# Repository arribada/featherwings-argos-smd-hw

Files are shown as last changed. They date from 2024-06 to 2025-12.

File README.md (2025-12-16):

N|Solid
# Feather Wings argos SMD breakout
## Description 

**Feather Wing for the ARGOS-SMD module. **

This breakout board can be used with a Feather board (from Adafruit) to connect the ARGOS-SMD module. 
It exposes the ARGOS-SMD module pins to the Feather board and includes a specific LDO to power the RF amplifier.

[Details of SMD argos repository.](https://github.com/arribada/argos-smd-hw)

This repository is an altium project with the production files. Please download the [hardware-lib](https://github.com/arribada/hardware-lib ) if you want full sources files (device sheet + library). 

## Components:

The RSPB tracker include the following components:
 - argos-smd
 - TPS63901 => power for RF amplifier

## Quick start

 - Connect Adafruit Feather nRF52840 (the Feather will provide 3V3 for SMD and VBAT or VBUS for Power Amplifier SMD)
 - Upload [Arduino sample](https://github.com/arribada/argos-smd-test-arduino) code or [Zephyr driver](https://github.com/arribada/argos-smd-driver-zephyr)
 - Communicate with KimGUI or Serial link with J6 connector
   or
 - Communicate to the SMD via the Adafruit Feather.

## Pin out 

Check Wiki page.

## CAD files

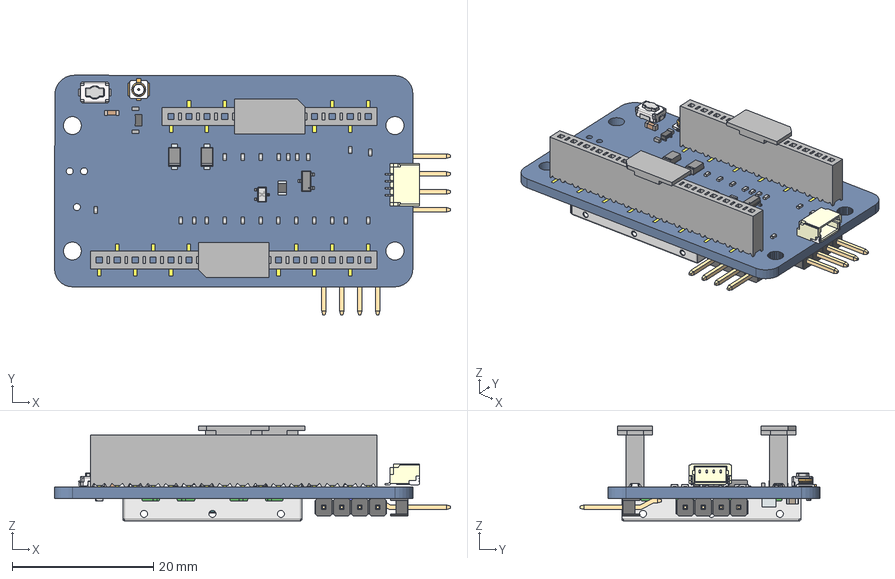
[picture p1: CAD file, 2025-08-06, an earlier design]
Project Outputs for Wings_SMD_Breakout/featherwings-argos-smd_v1.0/Wings_SMD_Breakout_v1.0.step
56.1 x 34.0 x 13.5 mm
M20-88904_MOULD x 2
M20-889_CONTACT x 8
36103255S
term1 x 12
term2 x 12
TL1015 BODY
TL1015 COVER
TL1015 ACTUATOR
TL1015 TERM x 2
Extruded x 60
Rect1 x 2
Rect2 x 2
Rect3 x 2
Rect4 x 2
Rect5 x 2
Rect6 x 2
Rect7 x 2
Rect8 x 2
Rect9 x 2
Rect10 x 2
Rect11 x 2
Chip Inductor 0603
A1
A2
A4
A5
A7
A8
A9
B1
B2
B3
B4
B5
B6
B7
B8
B9
C1
C2
C3
C4
C5
C6
C7
C8
D2
D3
D4
D5
D6
D7
D8
D9
E1
E2
E3
E4
E5
E6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

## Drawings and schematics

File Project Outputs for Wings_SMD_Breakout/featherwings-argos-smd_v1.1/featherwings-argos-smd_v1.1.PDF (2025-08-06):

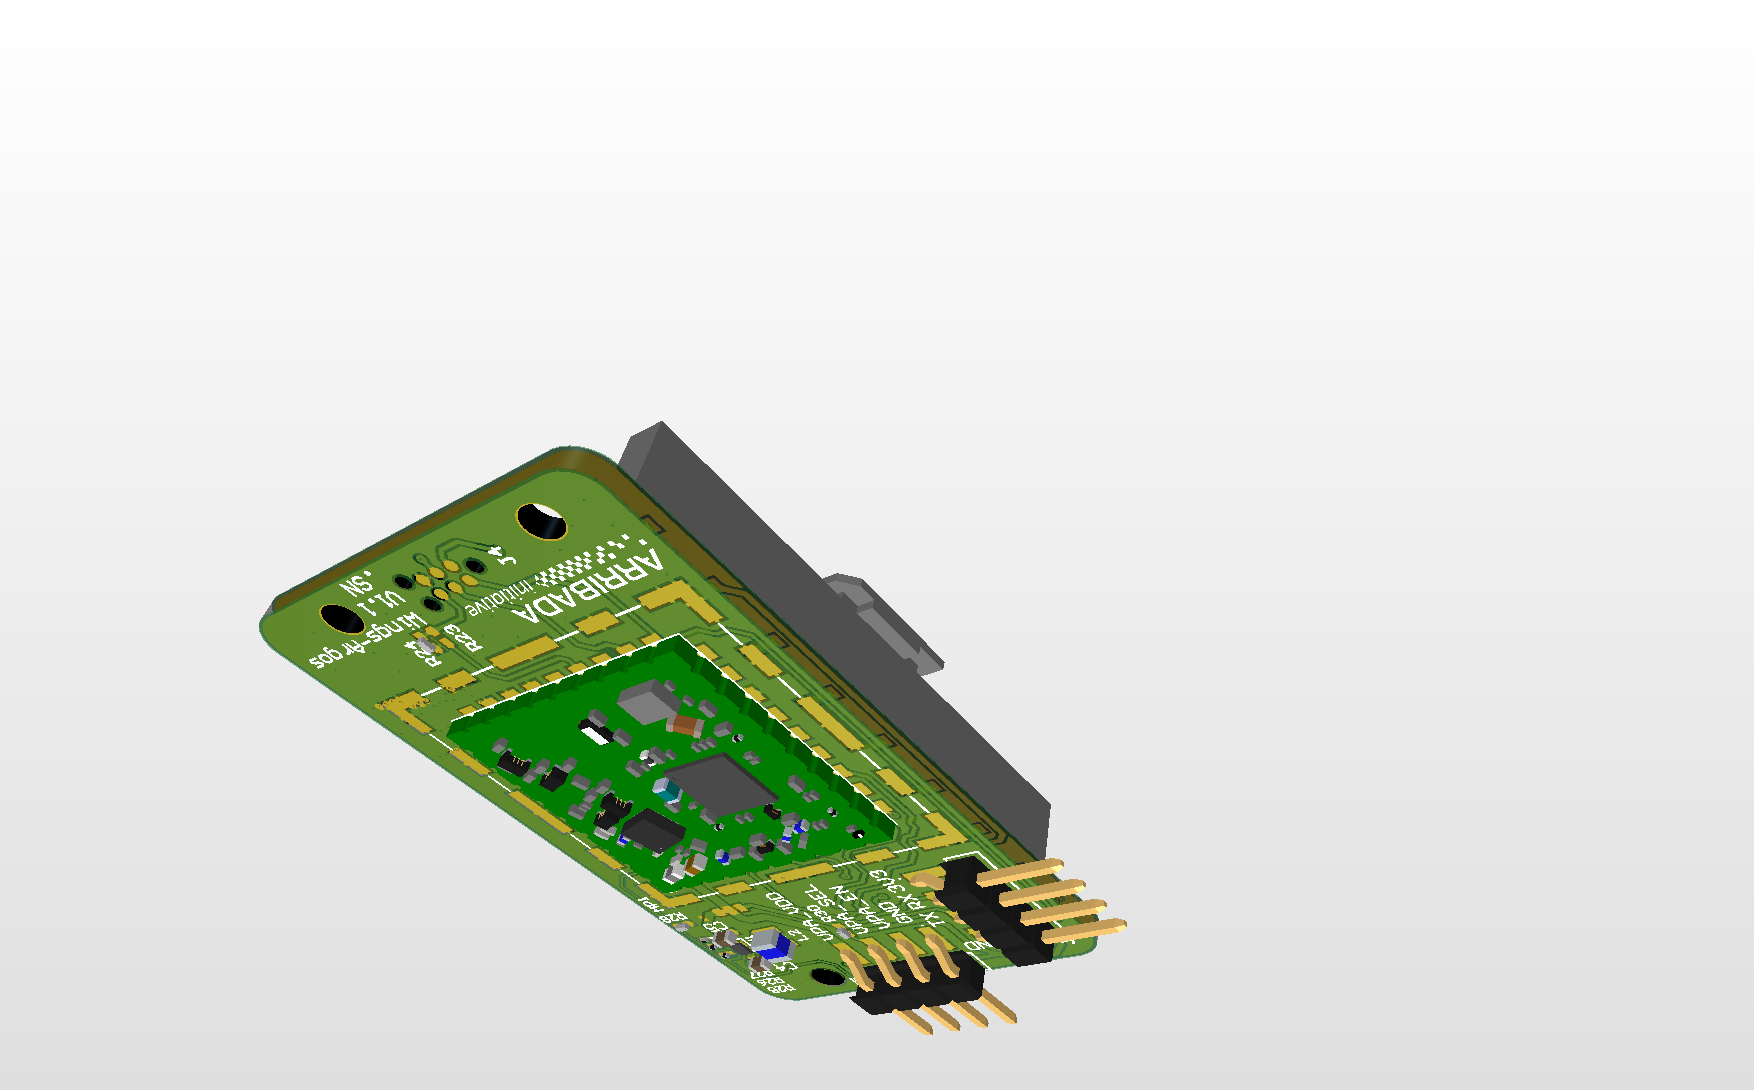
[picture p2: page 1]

D | D
C | C
B | B
A | A

Arribada Initiative
https://github.com/arribada contact@arribada.org
arribada.org
3 | UK - Portsmouth

## HorizonLink-Wings_Breakout

smd-wings | B
06/08/2025 | 15:22:21
C:\Users\fourn\Altium\AD25\Projects\Arribada\featherwings-argos-smd-hw\Project_Overview.SchDoc

Title

Size: | Reference:

Date:
File:

Revision:

Time: | Sheet | of
A4 | 1.1
Table of contents | Legend

General comment such as function title, configuration, ...

Sheet 2: SMD_Breakout | Text to be added to silkscreen.

Sheet 1: Project overview (this page)

# HorizonLink-Wings_Breakout

# smd-wings

Sheet 3: TPS63901_BuckBoost_lowIq_3V3_400mA

Device Sheets: | Warning text.

# OPEN HARDWARE LICENSE AGREEMENT

smd-wings

Feather wing for the ARGOS-SMD module. This breakout board can be used with a Feather board (from Adafruit) to connect the ARGOS-SMD module. It exposes the ARGOS-SMD module pins to the Feather board and includes a specific LDO to power the RF amplifier.

The Open Hardware License Agreement (“Agreement”) is a binding legal contract between you ("You") and the creators of this design, as represented by the Arribada Initiative, under the terms of the GNU General Public License version 3 (“GPLv3”). This license governs the use, modification, and distribution of the open-design PCB and any associated design files or materials (collectively referred to as the “Reference Material”).

By accessing, using, or modifying the Reference Material, You agree to be bound by the terms and conditions of the GPLv3. If you do not agree to these terms, do not use the Reference Material. Your use of the Reference Material constitutes acceptance of this Agreement.

The complete GNU General Public License version 3 can be found at www.gnu.org/licenses/gpl-3.0.html.

For more details about this open-design PCB project and its licensing, please visit the Arribada Initiative website or contact us directly.

Notes to generate the
board layout.

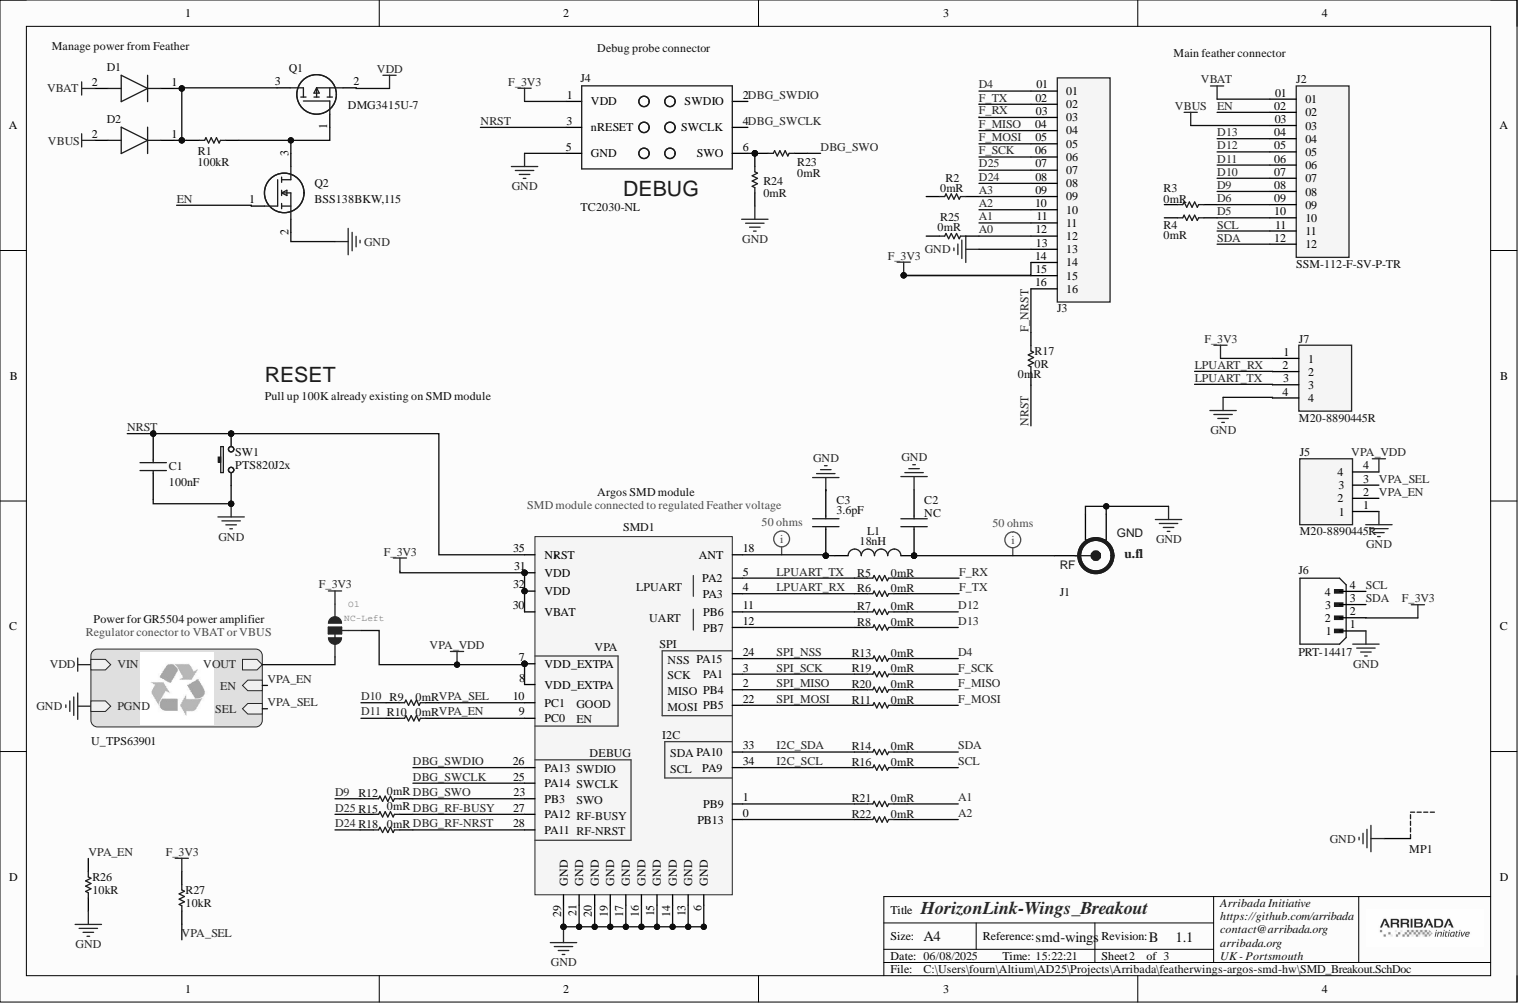
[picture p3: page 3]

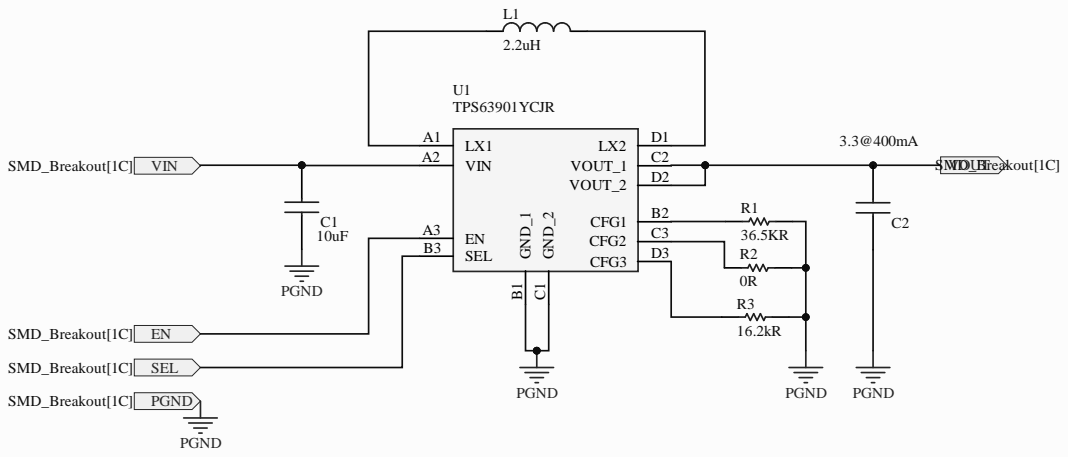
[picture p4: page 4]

# Board Stack Report

Stack Up | Layer Stack
Layer | Board Layer Stack | Name | Material | Thickness | Constant

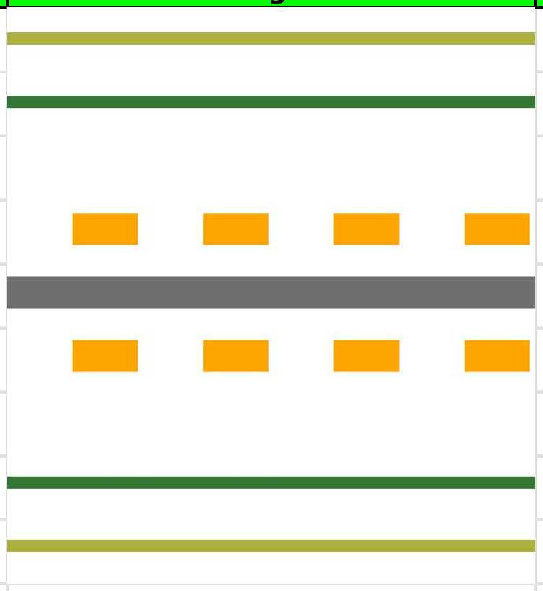
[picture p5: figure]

1 | | Top Overlay | | 0mil
2 | | Top Solder | SM-001 | 1mil | 4
3 | | Top Surface Finish | PbSn | 0.787mil
4 | | Top Layer | CF-004 | 1.378mil
5 | | Dielectric 1 | Core-043 | 59mil | 4.3
6 | | Bottom Layer | CF-004 | 1.378mil
7 | | Bottom Surface Finish | PbSn | 0.787mil
8 | | Bottom Solder | SM-001 | 1mil | 4
9 | | Bottom Overlay | | 0mil
| Height : 65.331mil

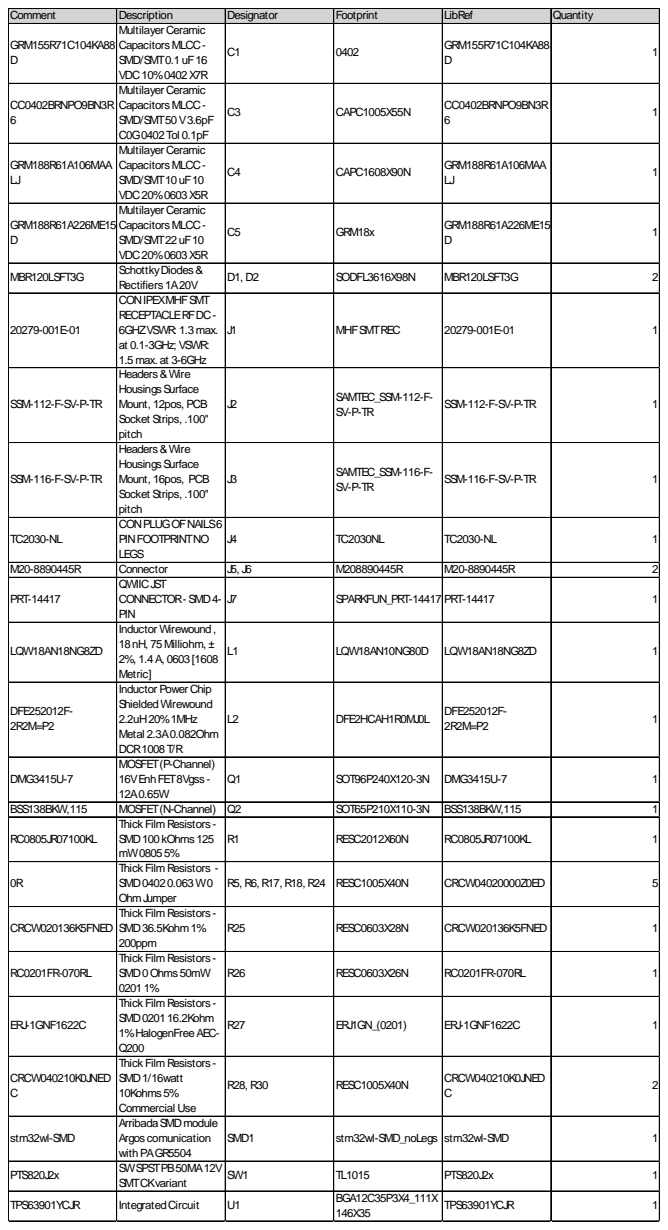
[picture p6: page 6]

Comment | Description | Designator | Footprint | LibRef | Quantity
GRM155R71C104KA88 | Multilayer Ceramic CapacitorsMLCC-SMD/SMT0.1 uF16 VDC10%0402X7R | C1 | 0402 | GRM155R71C104KA88 D | 1

CC0402BRNPO9BN3R 6 | Multilayer Ceramic CapacitorsMLCC-SMD/SMT50V3.6pF C0G0402Tol 0.1pF | C3 | CAPC1005X55N | CC0402BRNPO9BN3R 6 | 1

GRM188R61A106MAA LJ | Multilayer Ceramic CapacitorsMLCC-SMD/SMT10uF10 VDC20%0603X5R | C4 | CAPC1608X90N | GRM188R61A106MAA LJ | 1

GRM188R61A226ME15 D | Multilayer Ceramic CapacitorsMLCC-SMD/SMT22uF10 VDC20%0603X5R | C5 | GRM18x | GRM188R61A226ME15 D | 1

MBR120LSFT3G | SchottkyDiodes& Rectifiers1A20V | D1, D2 | SODFL3616X98N | MBR120LSFT3G | 2

20279-001E-01 | CONIPEXMHFSMT RECEPTACLERFDC-6GHZVSWR: 1.3 max. at 0.1-3GHz; VSWR: 1.5 max. at 3-6GHz | J1 | MHFSMTREC | 20279-001E-01 | 1

SSM-112-F-SV-P-TR | Headers&Wire HousingsSurface Mount, 12pos, PCB Socket Strips, .100" pitch | J2 | SAMTEC_SSM-112-F-SV-P-TR | SSM-112-F-SV-P-TR | 1

SSM-116-F-SV-P-TR | Headers&Wire HousingsSurface Mount, 16pos, PCB Socket Strips, .100" pitch | J3 | SAMTEC_SSM-116-F-SV-P-TR | SSM-116-F-SV-P-TR | 1

TC2030-NL | CONPLUGOFNAILS6 PINFOOTPRINTNO LEGS | J4 | TC2030NL | TC2030-NL | 1

M20-8890445R | Connector | J5, J6 | M208890445R | M20-8890445R | 2
PRT-14417 | QWIICJST CONNECTOR- SMD4-PIN | J7 | SPARKFUN_PRT-14417 PRT-14417 | | 1

LQW18AN18NG8ZD | Inductor Wirewound, 18nH, 75Milliohm, ± 2%, 1.4A, 0603[1608 Metric] | L1 | LQW18AN10NG80D | LQW18AN18NG8ZD | 1

DFE252012F-2R2M=P2 | Inductor Power Chip ShieldedWirewound 2.2uH20%1MHz Metal 2.3A0.082Ohm DCR1008T/R | L2 | DFE2HCAH1R0MJ0L | DFE252012F-2R2M=P2 | 1

DMG3415U-7 | MOSFET(P-Channel) 16VEnhFET8Vgss -12A0.65W | Q1 | SOT96P240X120-3N | DMG3415U-7 | 1

BSS138BKW,115 | MOSFET(N-Channel) | Q2 | SOT65P210X110-3N | BSS138BKW,115 | 1
RC0805JR07100KL | Thick Film Resistors -SMD100kOhms125 mW08055% | R1 | RESC2012X60N | RC0805JR07100KL | 1
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

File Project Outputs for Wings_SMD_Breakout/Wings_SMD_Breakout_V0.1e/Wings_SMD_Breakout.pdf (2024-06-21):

D | D
C | C
B | B
A | A

Arribada Initiative
https://github.com/arribada contact@arribada.org
arribada.org
3 | UK - Portsmouth

## HorizonLink-Wings_Breakout

wings-smd | 0.1
21/06/2024 | 11:32:49
D:\Altium\Projects\stm32wl-dev\Projects\Wings_SMD_Breakout\Project_Overview.SchDoc

Title

Size: | Reference:

Date:
File:

Revision:

Time: | Sheet | of
A4 | e
Table of contents | Legend

General comment such as function title, configuration, ...

Sheet 2: SMD_Breakout | Text to be added to silkscreen.

Sheet 1: Project overview (this page)

# HorizonLink-Wings_Breakout

# wings-smd

Sheet 3: TPS62A01DRL_Buck_3V3

Device Sheets: | Warning text.

# OPEN PLATFORM LICENSE AGREEMENT

The Open Platform License Agreement (“Agreement”) is a binding legal contract between you ("You")

and STMicroelectronics International N.V. (“ST”), a company incorporated under the laws of the

Netherlands acting for the purpose of this Agreement through its Swiss branch 39, Chemin du

Champ des Filles, 1228 Plan-les-Ouates, Geneva, Switzerland.

By using the enclosed reference designs, schematics, PC board layouts, and documentation, in hardcopy

or CAD tool file format (collectively, the “Reference Material”), You are agreeing to be bound by

the terms and conditions of this Agreement. Do not use the Reference Material until You have read

and agreed to this Agreement terms and conditions. The use of the Reference Material automatically

implies the acceptance of the Agreement terms and conditions.

The complete Open Platform License Agreement can be found on www.st.com/opla.

U_SMD_Breakout
SMD_Breakout.SchDoc

Notes to generate the
board layout.

Feather wing for the ARGOS-SMD module. This breakout board can be used with a Feather board (from Adafruit) to connect the ARGOS-SMD module. It exposes the ARGOS-SMD module pins to the Feather board and includes a specific LDO to power the RF amplifier.

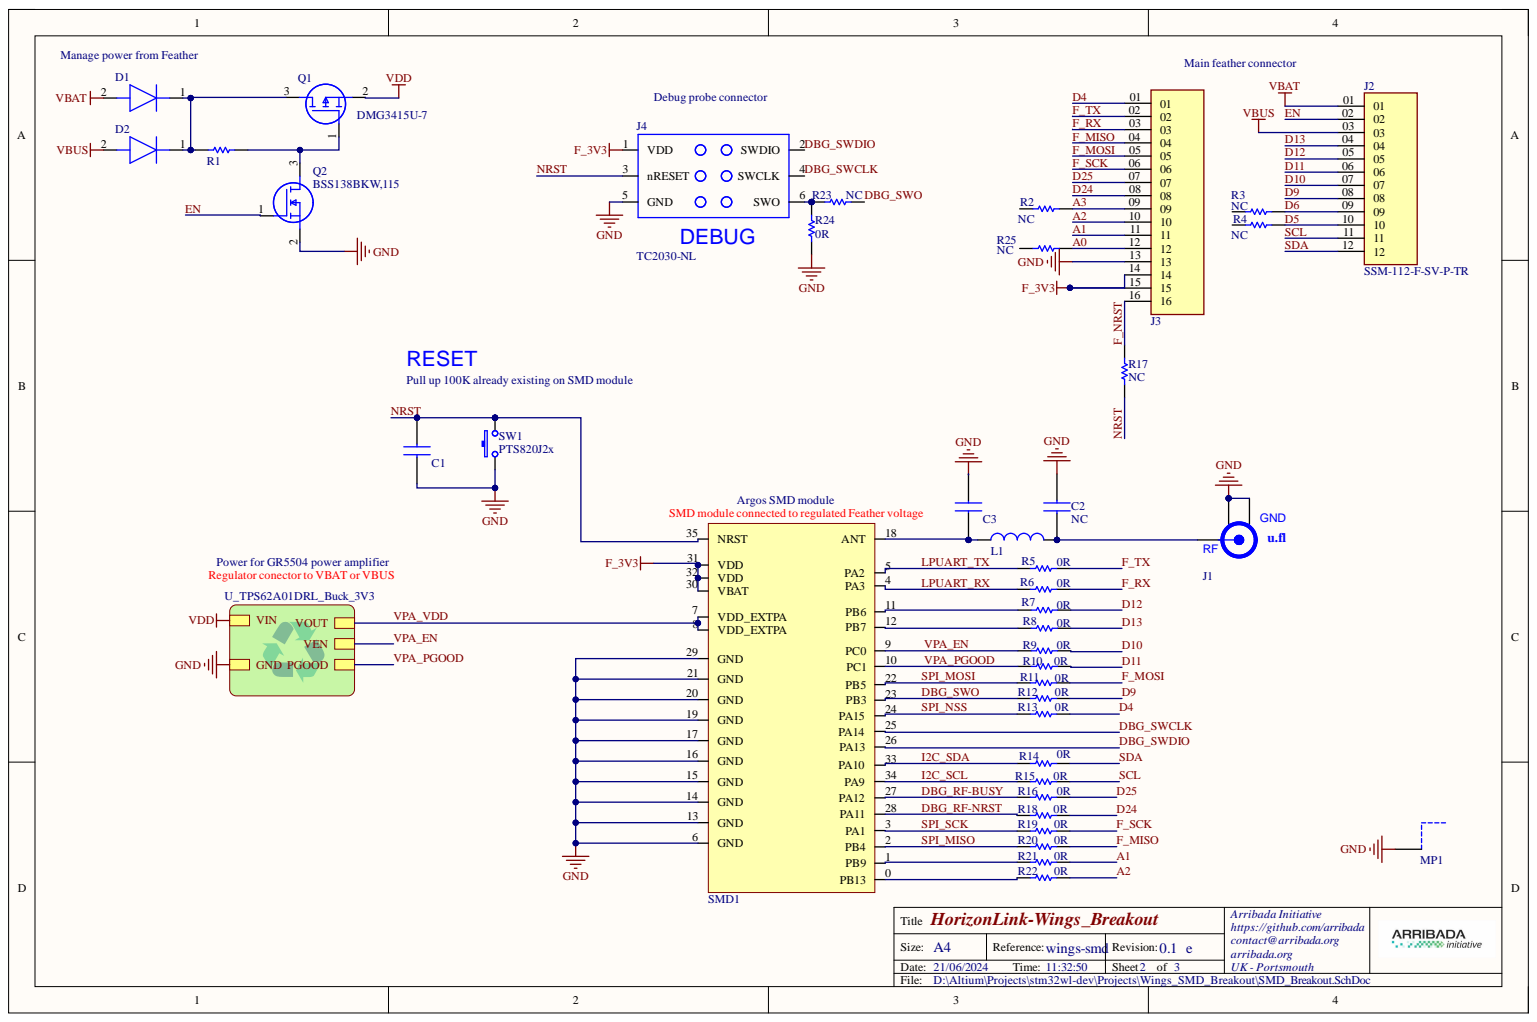
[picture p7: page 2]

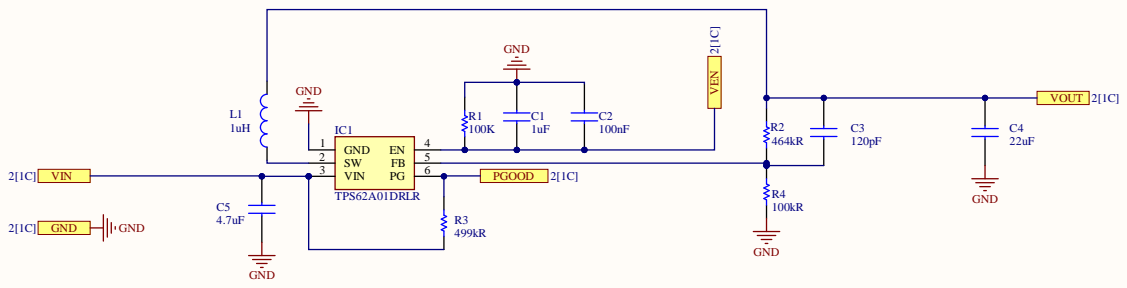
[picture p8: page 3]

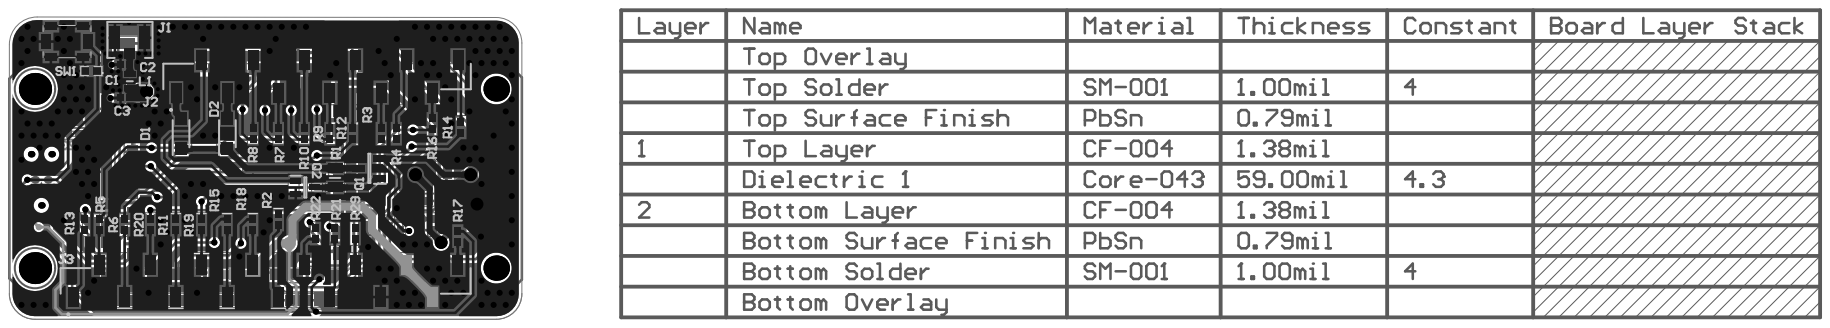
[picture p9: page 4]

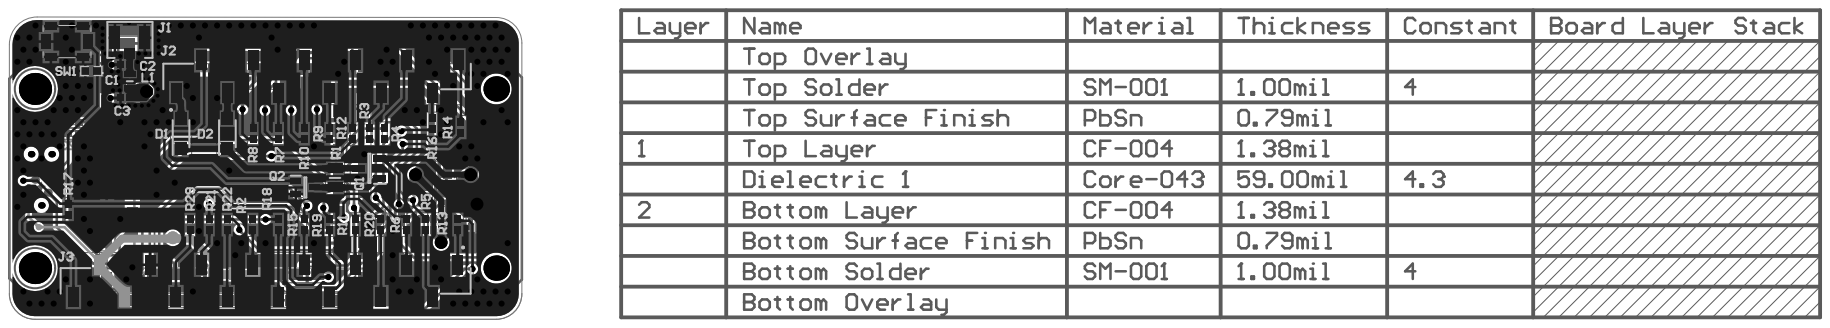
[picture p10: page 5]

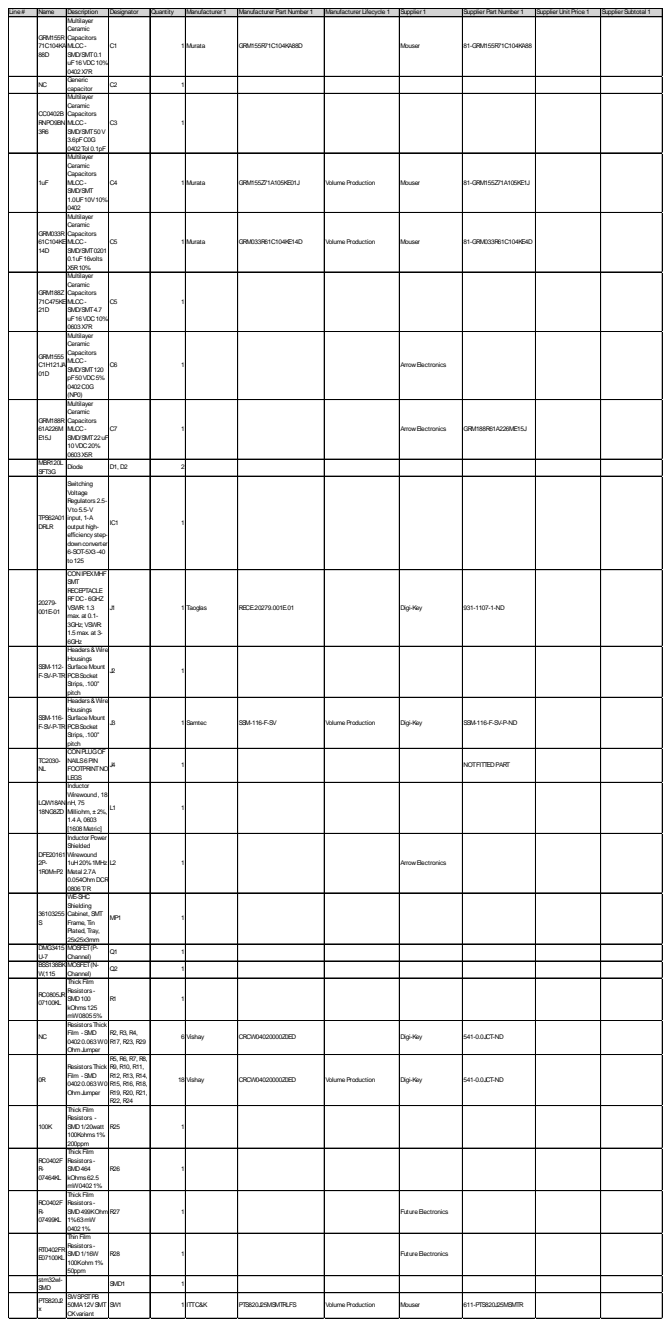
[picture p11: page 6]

NC | Generic capacitor | C2 | 1

CC0402B RNPO9BN 3R6 | Multilayer Ceramic Capacitors MLCC-SMD/SMT50V 3.6pFC0G 0402Tol 0.1pF | C3 | 1

1uF | Multilayer Ceramic Capacitors MLCC-SMD/SMT 1.0UF10V10% 0402 | C4 | 1 Murata | GRM155Z71A105KE01J | VolumeProduction | Mouser | 81-GRM155Z71A105KE1J

GRM033R 61C104KE 14D | Multilayer Ceramic Capacitors MLCC-SMD/SMT0201 0.1uF16volts X5R10% | C5 | 1 Murata | GRM033R61C104KE14D | VolumeProduction | Mouser | 81-GRM033R61C104KE4D

GRM188Z 71C475KE 21D | Multilayer Ceramic Capacitors MLCC-SMD/SMT4.7 uF16VDC10% 0603X7R | C5 | 1

GRM1555 C1H121JA 01D | Multilayer Ceramic Capacitors MLCC-SMD/SMT120 pF50VDC5% 0402C0G (NP0) | C6 | 1 | | | ArrowElectronics

GRM188R 61A226M E15J | Multilayer Ceramic Capacitors MLCC-SMD/SMT22uF 10VDC20% 0603X5R | C7 | 1 | | | ArrowElectronics | GRM188R61A226ME15J

MBR120L SFT3G | Diode | D1, D2 | 2

TPS62A01 DRLR | Switching Voltage Regulators2.5-Vto5.5-V input, 1-A output high-efficiency step-downconverter 6-SOT-5X3-40 to125 | IC1 | 1

20279-001E-01 | CONIPEXMHF SMT RECEPTACLE RFDC- 6GHZ VSWR: 1.3 max. at 0.1-3GHz; VSWR: 1.5 max. at 3-6GHz | J1 | 1 Taoglas | RECE.20279.001E.01 | | Digi-Key | 931-1107-1-ND

SSM-112-F-SV-P-TR | Headers&Wire Housings Surface Mount PCBSocket Strips, .100" pitch | J2 | 1

SSM-116-F-SV-P-TR | Headers&Wire Housings Surface Mount PCBSocket Strips, .100" pitch | J3 | 1 Samtec | SSM-116-F-SV | VolumeProduction | Digi-Key | SSM-116-F-SV-P-ND

TC2030-NL | CONPLUGOF NAILS6PIN FOOTPRINTNO LEGS | J4 | 1 | | | | NOTFITTEDPART

LQW18AN 18NG8ZD | Inductor Wirewound, 18 nH, 75 Milliohm, ±2%, 1.4A, 0603 [1608Metric] | L1 | 1

DFE20161 2P-1R0M=P2 | Inductor Power Shielded Wirewound 1uH20%1MHz Metal 2.7A 0.054OhmDCR 0806T/R | L2 | 1 | | | ArrowElectronics

36103255 S | WE-SHC Shielding Cabinet, SMT Frame, Tin Plated, Tray, 25x25x3mm | MP1 | 1

DMG3415 U-7 | MOSFET(P-Channel) | Q1 | 1

BSS138BK W,115 | MOSFET(N-Channel) | Q2 | 1

RC0805JR 07100KL | Thick Film Resistors -SMD100 kOhms125 mW08055% | R1 | 1

NC | ResistorsThick Film - SMD 04020.063W0 OhmJumper | R2, R3, R4, R17, R23, R29 | 6 Vishay | CRCW04020000Z0ED | | Digi-Key | 541-0.0JCT-ND

0R | ResistorsThick Film - SMD 04020.063W0 OhmJumper | R5, R6, R7, R8, R9, R10, R11, R12, R13, R14, R15, R16, R18, R19, R20, R21, R22, R24 | 18 Vishay | CRCW04020000Z0ED | VolumeProduction | Digi-Key | 541-0.0JCT-ND

100K | Thick Film Resistors -SMD1/20watt 100Kohms1% 200ppm | R25 | 1
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

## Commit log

2024-06-21 PCB produced and tested
    [Project_Overview.SchDoc, SMD_Breakout.SchDoc, Wings_SMD_Breakout.PrjPcb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]
2024-09-19 Update schematics with new LDO
    [SMD_Breakout.SchDoc, Wings_SMD_Breakout.PrjPcb, Wings_SMD_Breakout_v1.0.PcbDoc]
2024-11-22 clean project output
    [Project_Overview.SchDoc, SMD_Breakout.SchDoc, Wings_SMD_Breakout.PrjPcb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]
2025-08-06 Small fix for new batch v1.1
    - Add pulldown to LDO PA ENable
    - Add Pull-up to PSEL (VPA)
    - Add option to share 3.3V to VPA
    [SMD_Breakout.SchDoc, Wings_SMD_Breakout_v1.0.step, Wings_SMD_Breakout_v1.1.PcbDoc]
2025-08-06 Change nolegs SMD by shortlegs one
    [Wings_SMD_Breakout.PrjPcb, Wings_SMD_Breakout_v1.1.PcbDoc]
2025-11-04 Add device sheet TPS63901
    [TPS63901_BuckBoost_lowIq_3V3_400mA.SchDoc, Wings_SMD_Breakout.PrjPcb, Wings_SMD_Breakout_v1.1.PcbDoc]
